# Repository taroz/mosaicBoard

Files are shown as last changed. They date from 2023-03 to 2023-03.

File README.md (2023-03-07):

# mosaic-Board
## Introduction
- **mosaic-Board** = [**mosaic**](https://github.com/septentrio-gnss/mosaicHAT) + **micro SD card** + **Ethernet** + **Case**
- We use [Septentrio's mosaic-X5](https://www.septentrio.com/en/products/gnss-receivers/rover-base-receivers/receivers-module/mosaic) GNSS module which is a **low-cost** and **survey-grade** GNSS receiver
- This project is inspired by [mosaicHAT](https://github.com/septentrio-gnss/mosaicHAT) and extends it further. Thanks to the wonderful project [mosaicHAT](https://github.com/septentrio-gnss/mosaicHAT)!
- License: [Creative Commons Attribution Share-Alike License](https://creativecommons.org/licenses/by-sa/4.0/). and [Open Source HW](https://www.oshwa.org/definition/)  
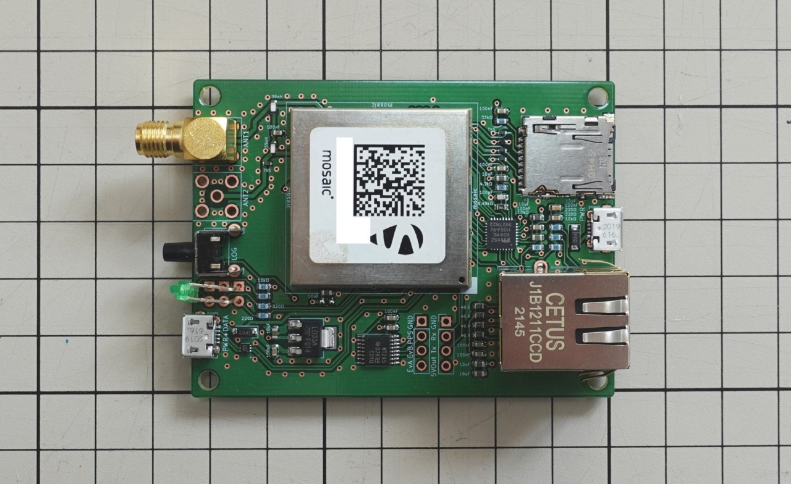
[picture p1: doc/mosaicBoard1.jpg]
 
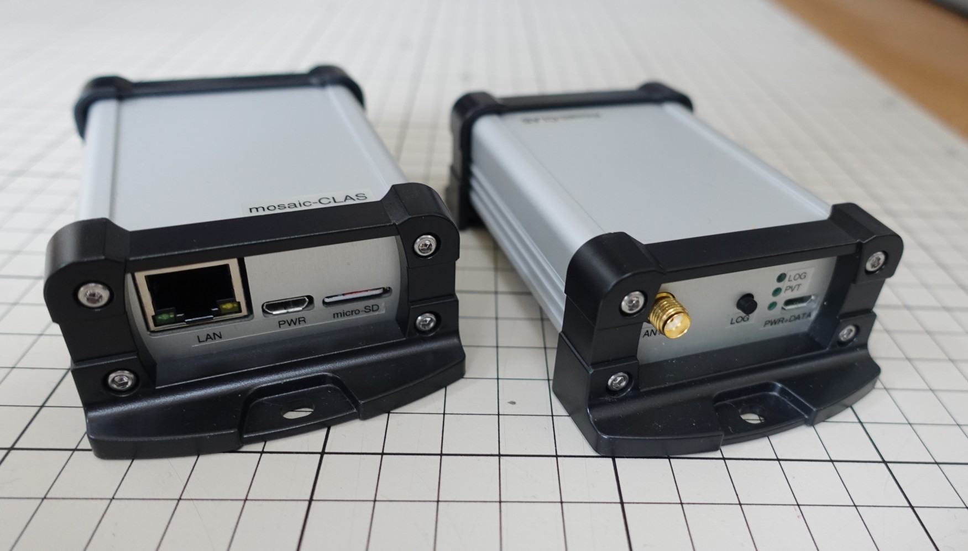
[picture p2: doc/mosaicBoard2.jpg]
 

## Features
- The mosaic-Board has a RJ45 LAN connector and can easily distribute GNSS reference station data over the Internet without a PC by using mosaic's built-in Ntrip Caster or Ntrip Server.
- The micro SD card enables use as a GNSS logger without a PC.

## Board
- The design of the board is based on the original [mosaicHAT](https://github.com/septentrio-gnss/mosaicHAT).
  - RJ45 connector has been added
  - Micro SD card and log button have been added for data logging capability
- [KiCAD files](./board/KiCAD) and [gerber](./board/gerber)
- Bill of Materials (BOM) is [here](./board/BOM.xlsx)                                 
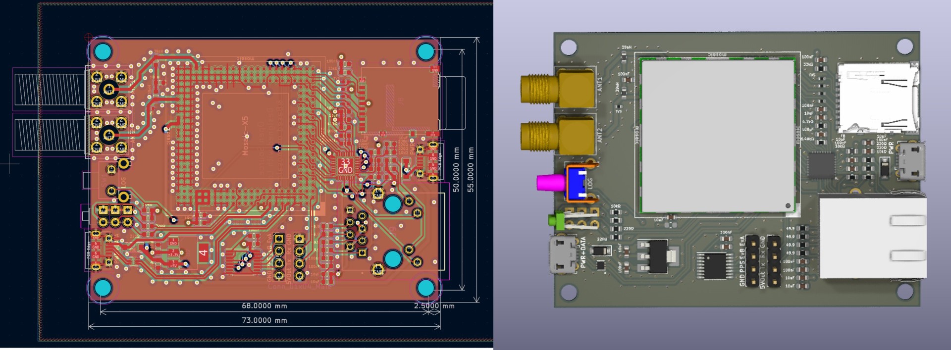
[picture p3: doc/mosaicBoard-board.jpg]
  

## Case
- Metal case design data (Fusion 360, STEP) is [available](./case)
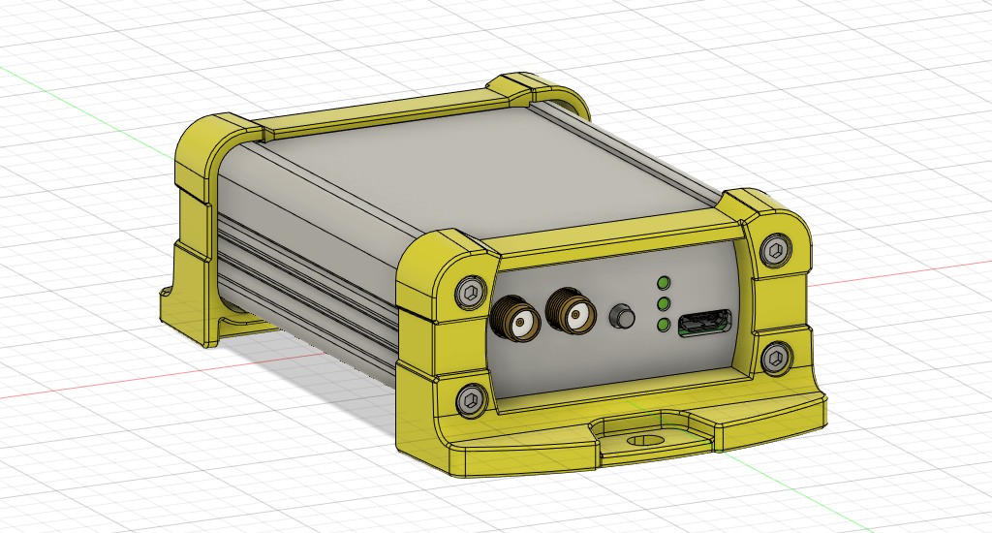
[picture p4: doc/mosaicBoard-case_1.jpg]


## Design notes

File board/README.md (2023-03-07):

# mosaic-Board Design Files
- We used KiCAD 6 for our design. [KiCAD 6 or later](https://www.kicad.org/) must be installed in order to edit the design data.
- BOM
  - `BOM.xlsx` shows the parts to be used and where to obtain them.

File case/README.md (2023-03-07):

# mosaic-Board Case
## Case
- TAKACHI EXP7-3-9, EXPE7-3-9, EXPF7-3-9 or EXEF7-3-9 
  - **EXP7-3-9** https://www.takachi-enclosure.com/products/EXP
  - **EXPE7-3-9** https://www.takachi-enclosure.com/products/EXPE (EMC shield)
  - **EXPF7-3-9** https://www.takachi-enclosure.com/products/EXPF (with flanged frame)
  - **EXEF7-3-9** https://www.takachi-enclosure.com/products/EXEF (EMC shield with flanged frame)
  
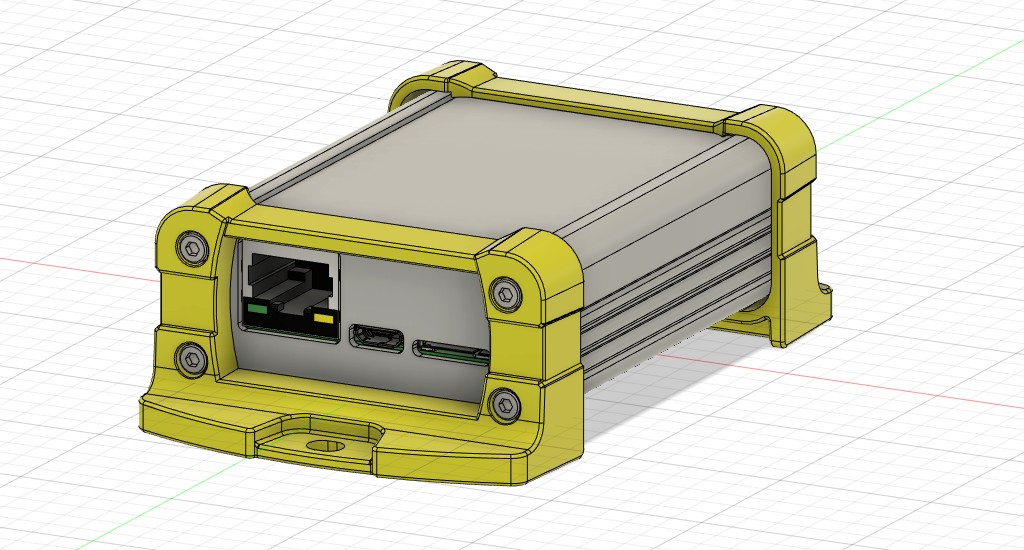
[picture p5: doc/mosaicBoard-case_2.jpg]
  
- Metalworking of the panel is required.

## 3D data
- `Fusion360/mosaicBoard-case.f3z`: Fusion 360 design data
- `mosaicBoard-case.step`: STEP file
- `panel1.step`: Panel STEP file
- `panel2.step`: Panel STEP file

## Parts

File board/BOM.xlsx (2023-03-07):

Designator | Footprint | Quantity | Value | MPN
C1, C12, C14, C15, C16, C19, C3, C4, C5, C8 | C_0603_1608Metric | 10 | 100nF
C10 | C_0603_1608Metric | 1 | 1uF
C11, C13, C18, C2, C6, C9 | C_0603_1608Metric | 6 | 10uF
C17 | C_0603_1608Metric | 1 | 100pF
C7 | C_0603_1608Metric | 1 | un-assembled
D1, D2 | D_SOD-123 | 2 | MBRX120LF-TP | MBRX120LF-TP | https://www.digikey.com/product-detail/en/micro-commercial-co/MBRX120LF-TP/MBRX120LF-TPMSCT-ND/2041570
D10, D11, D12, D13, D9 | R_0402_1005Metric | 5 | D_TVS | SESD0402X1BN-0010-098 | https://www.digikey.com/en/products/detail/littelfuse-inc/SESD0402X1BN-0010-098/5233522
D3 | LED_D1.8mm_W1.8mm_H2.4mm_Horizontal_O1.27mm_Z1.6mm | 1 | LED | TLUG2401 | https://www.digikey.com/en/products/detail/vishay-semiconductor-opto-division/TLUG2401/4074586
D4 | LED_D1.8mm_W1.8mm_H2.4mm_Horizontal_O3.81mm_Z4.9mm | 1 | LED | TLUG2401 | https://www.digikey.com/en/products/detail/vishay-semiconductor-opto-division/TLUG2401/4074586
D5 | LED_D1.8mm_W1.8mm_H2.4mm_Horizontal_O6.35mm_Z8.2mm | 1 | LED | TLUG2401 | https://www.digikey.com/en/products/detail/vishay-semiconductor-opto-division/TLUG2401/4074586
FB1 | L_0603_1608Metric | 1 | Ferrite_Bead_Small | BLM18RK601SN1D | https://www.digikey.com/en/products/detail/murata-electronics/BLM18RK601SN1D/1948332
FL1 | ST_UQFN-6L_1.5x1.7mm_Pitch0.5mm | 1 | ECMF02-2AMX6 | ECMF02-2AMX6 | https://www.digikey.com/en/products/detail/stmicroelectronics/ECMF02-2AMX6/2440273
IC1 | QFN50P500X500X90-33N-D | 1 | KSZ8041NLI-TR | KSZ8041NLI-TR | https://www.digikey.com/en/products/detail/microchip-technology/KSZ8041NLI-TR/1640276
J1, J2 | SMA_Amphenol_132203-12_Horizontal_mod | 2 | Conn_Coaxial | 132136 | https://www.digikey.com/en/products/detail/amphenol-rf/132136/1011909
J10, J3 | USB_Micro-B_Molex-105017-0001 | 2 | USB_B_Micro | 1050170001 | https://www.digikey.com/en/products/detail/molex/1050170001/2350832
J4, J5 | PinHeader_1x04_P2.54mm_Vertical | 2 | Conn_01x04_Male
J8 | microSD_HC_Hirose_DM3AT-SF-PEJM5 | 1 | Micro_SD_Card | DM3AT-SF-PEJM5 | https://www.digikey.com/en/products/detail/hirose-electric-co-ltd/DM3AT-SF-PEJM5/2533565
J9 | J1B1211CCD | 1 | J1B1211CCD | J1B1211CCD | https://www.digikey.com/en/products/detail/wiznet/J1B1211CCD/7604176
L1, L2 | L_0603_1608Metric | 2 | 39nH
R1, R15, R2, R4, R5 | R_0603_1608Metric | 5 | 220
R10, R3, R8, R9 | R_0603_1608Metric | 4 | 49.9
R11, R14, R7 | R_0603_1608Metric | 3 | 10K
R12 | R_0603_1608Metric | 1 | 6.49K
R13 | R_0603_1608Metric | 1 | 4.7K
R6 | R_0603_1608Metric | 1 | 33K
SW1 | SW_Tactile_SKHH_Angled | 1 | SW_Push | SKHHLQA010 | https://www.mouser.com/ProductDetail/Alps-Alpine/SKHHLQA010
U1 | mosaic_X5 | 1 | mosaic-X5 | 410322 | https://www.digikey.com/en/products/detail/septentrio-inc/410322/12503897
U2 | SOT-223 | 1 | LD1117AS33TR | LD1117AS33TR | https://www.digikey.com/product-detail/en/stmicroelectronics/LD1117AS33TR/497-1228-1-ND/586228
U3 | TSSOP-16_4.4x5mm_P0.65mm | 1 | SN74AVC4T245PW | SN74AVC4T245PWR | https://www.digikey.com/product-detail/en/texas-instruments/SN74AVC4T245PWR/296-18056-1-ND/770944
Case |  | 1 | TAKACHI | EXEF7-3-9 | https://www.takachi-enclosure.com/products/EXEF

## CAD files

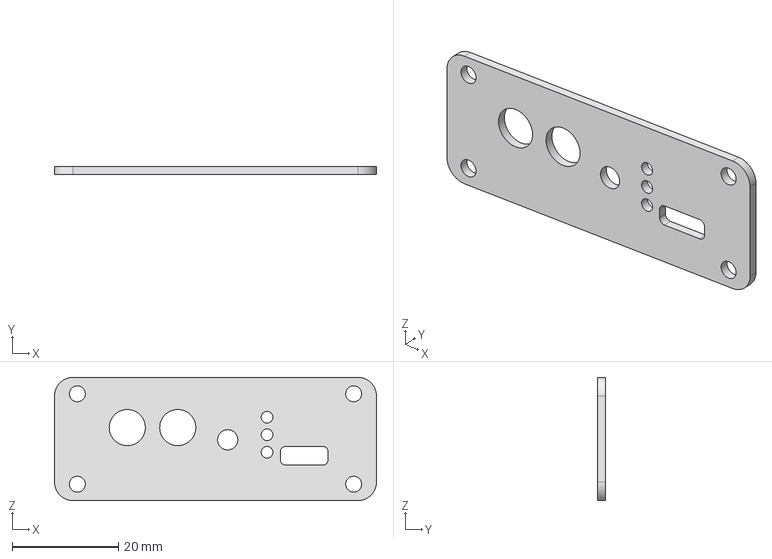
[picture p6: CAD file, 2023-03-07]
case/panel1.step
60.6 x 1.50 x 23.2 mm

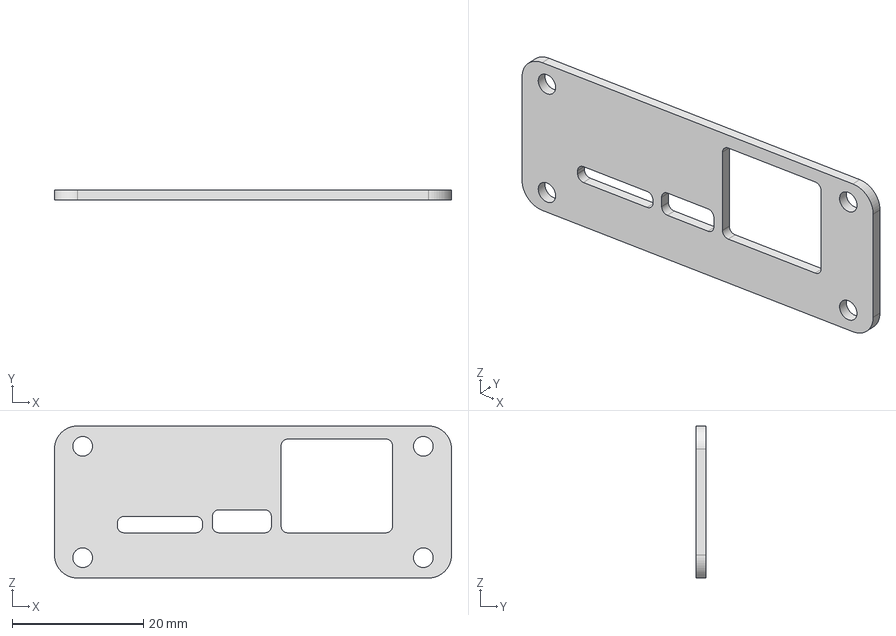
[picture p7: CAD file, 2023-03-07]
case/panel2.step
60.6 x 1.50 x 23.2 mm

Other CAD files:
case/Fusion360/mosaicBoard-case.f3z

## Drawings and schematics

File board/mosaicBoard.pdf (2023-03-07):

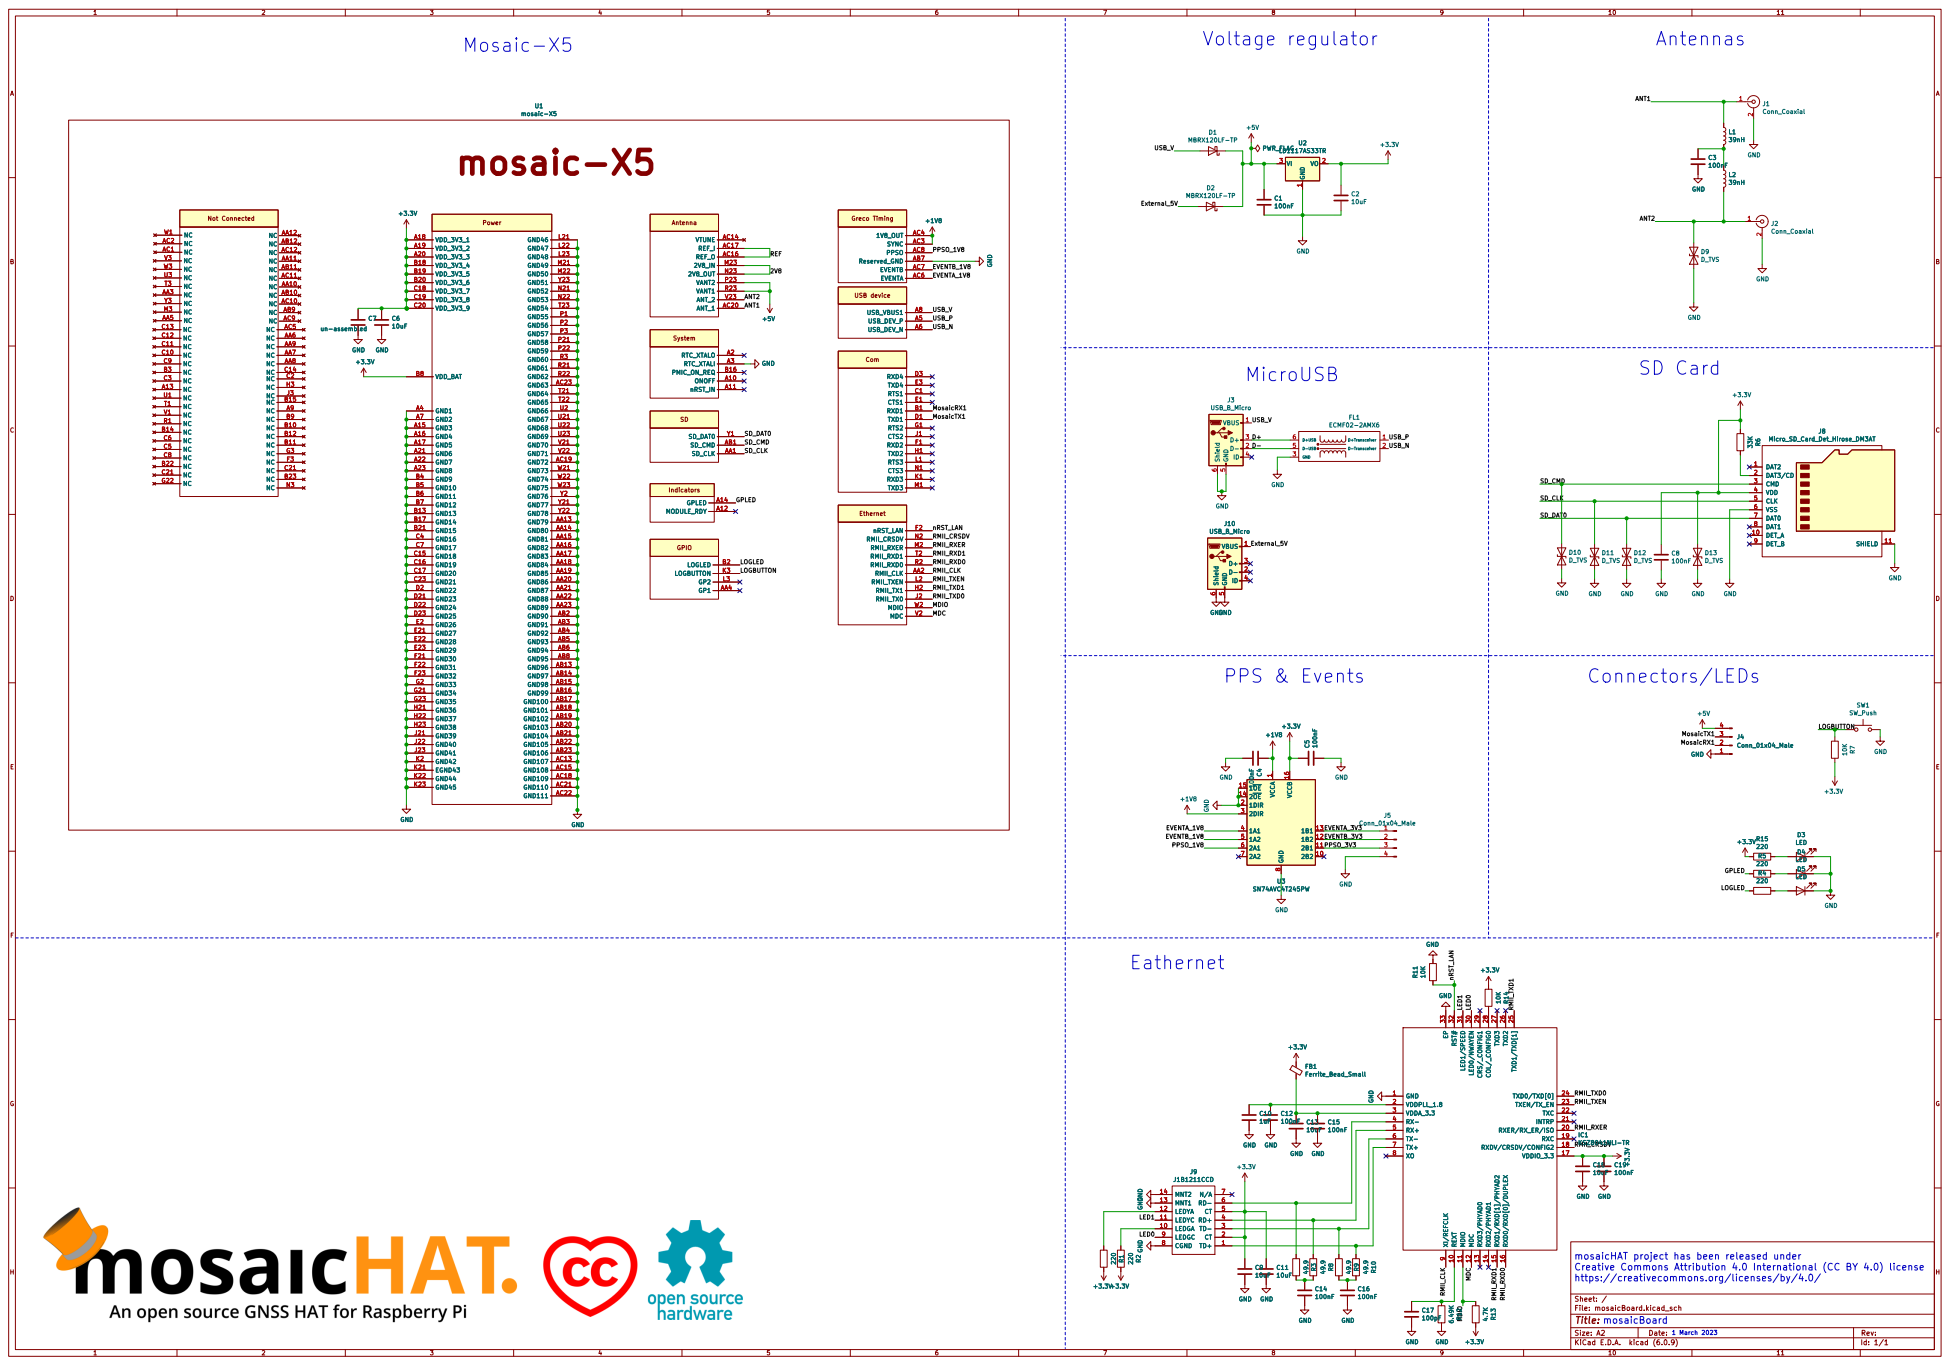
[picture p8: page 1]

mosaicHAT project has been released under
Creative Commons Attribution 4.0 International (CC BY 4.0) license
https://creativecommons.org/licenses/by/4.0/ 1 March 2023 mosaicBoard

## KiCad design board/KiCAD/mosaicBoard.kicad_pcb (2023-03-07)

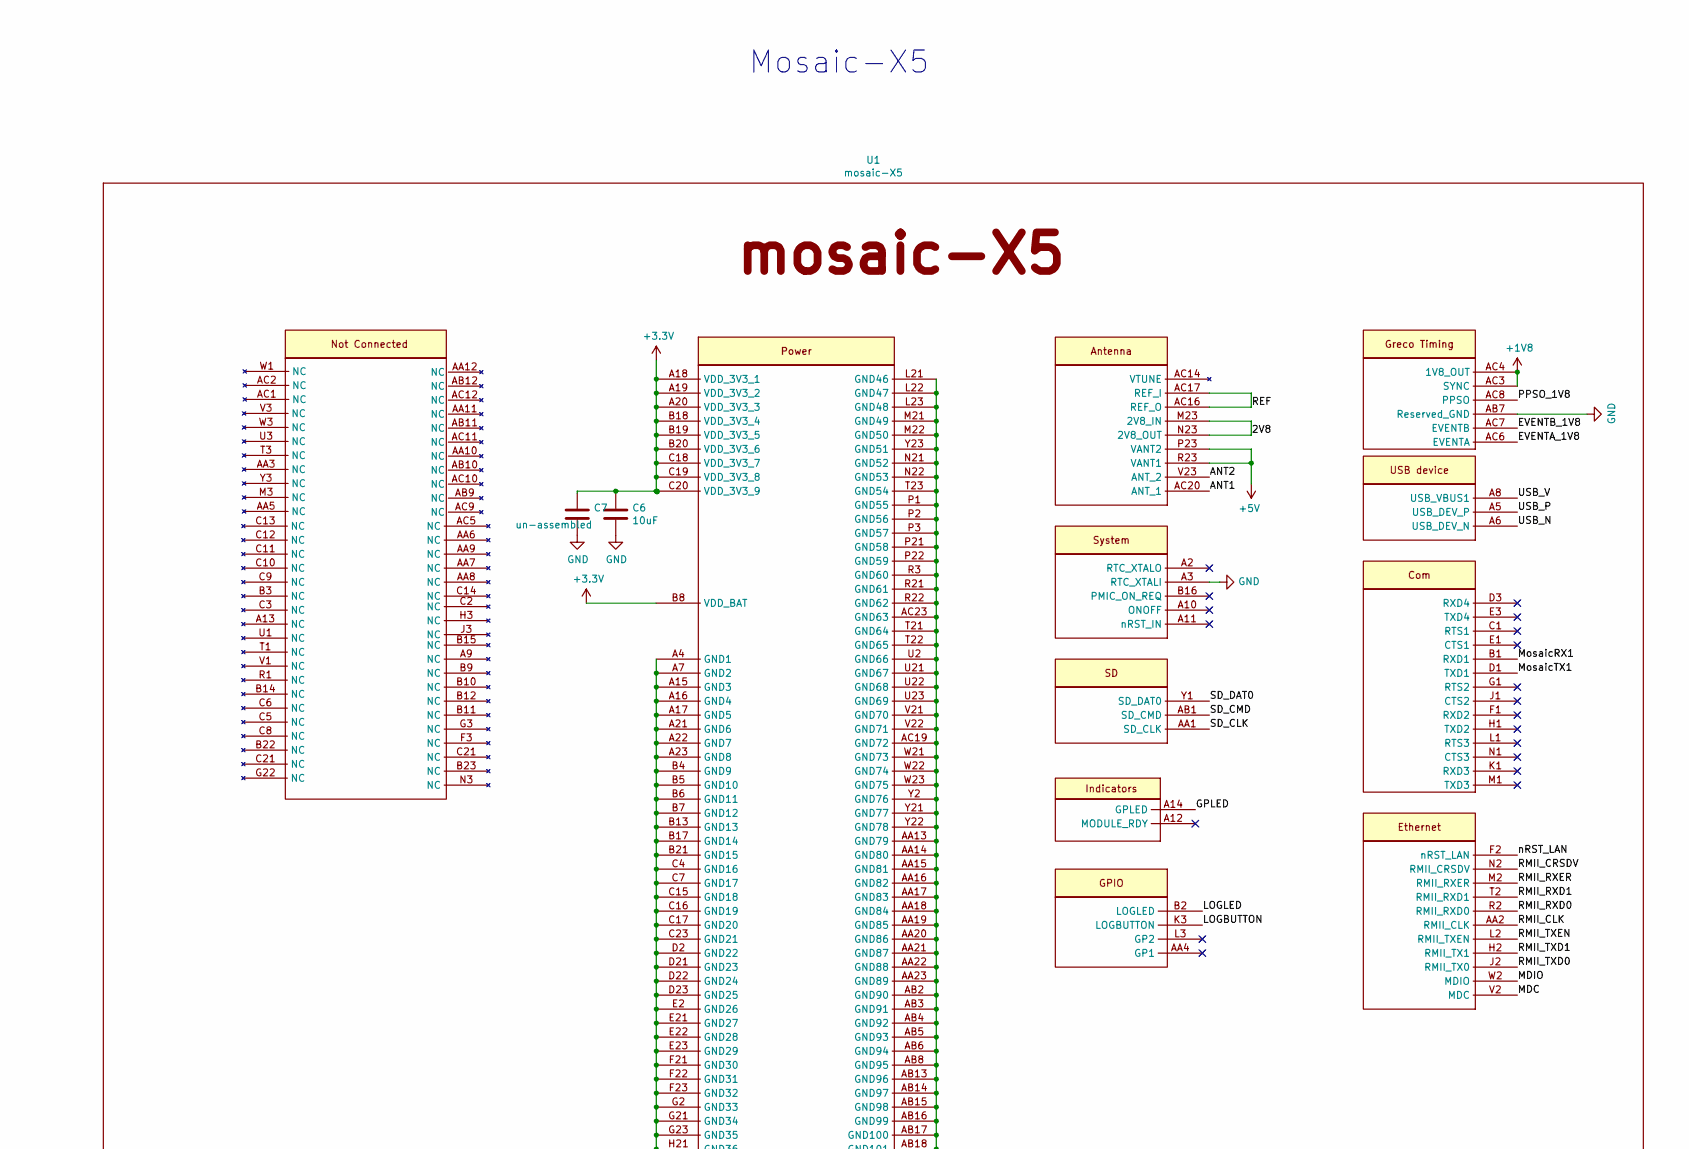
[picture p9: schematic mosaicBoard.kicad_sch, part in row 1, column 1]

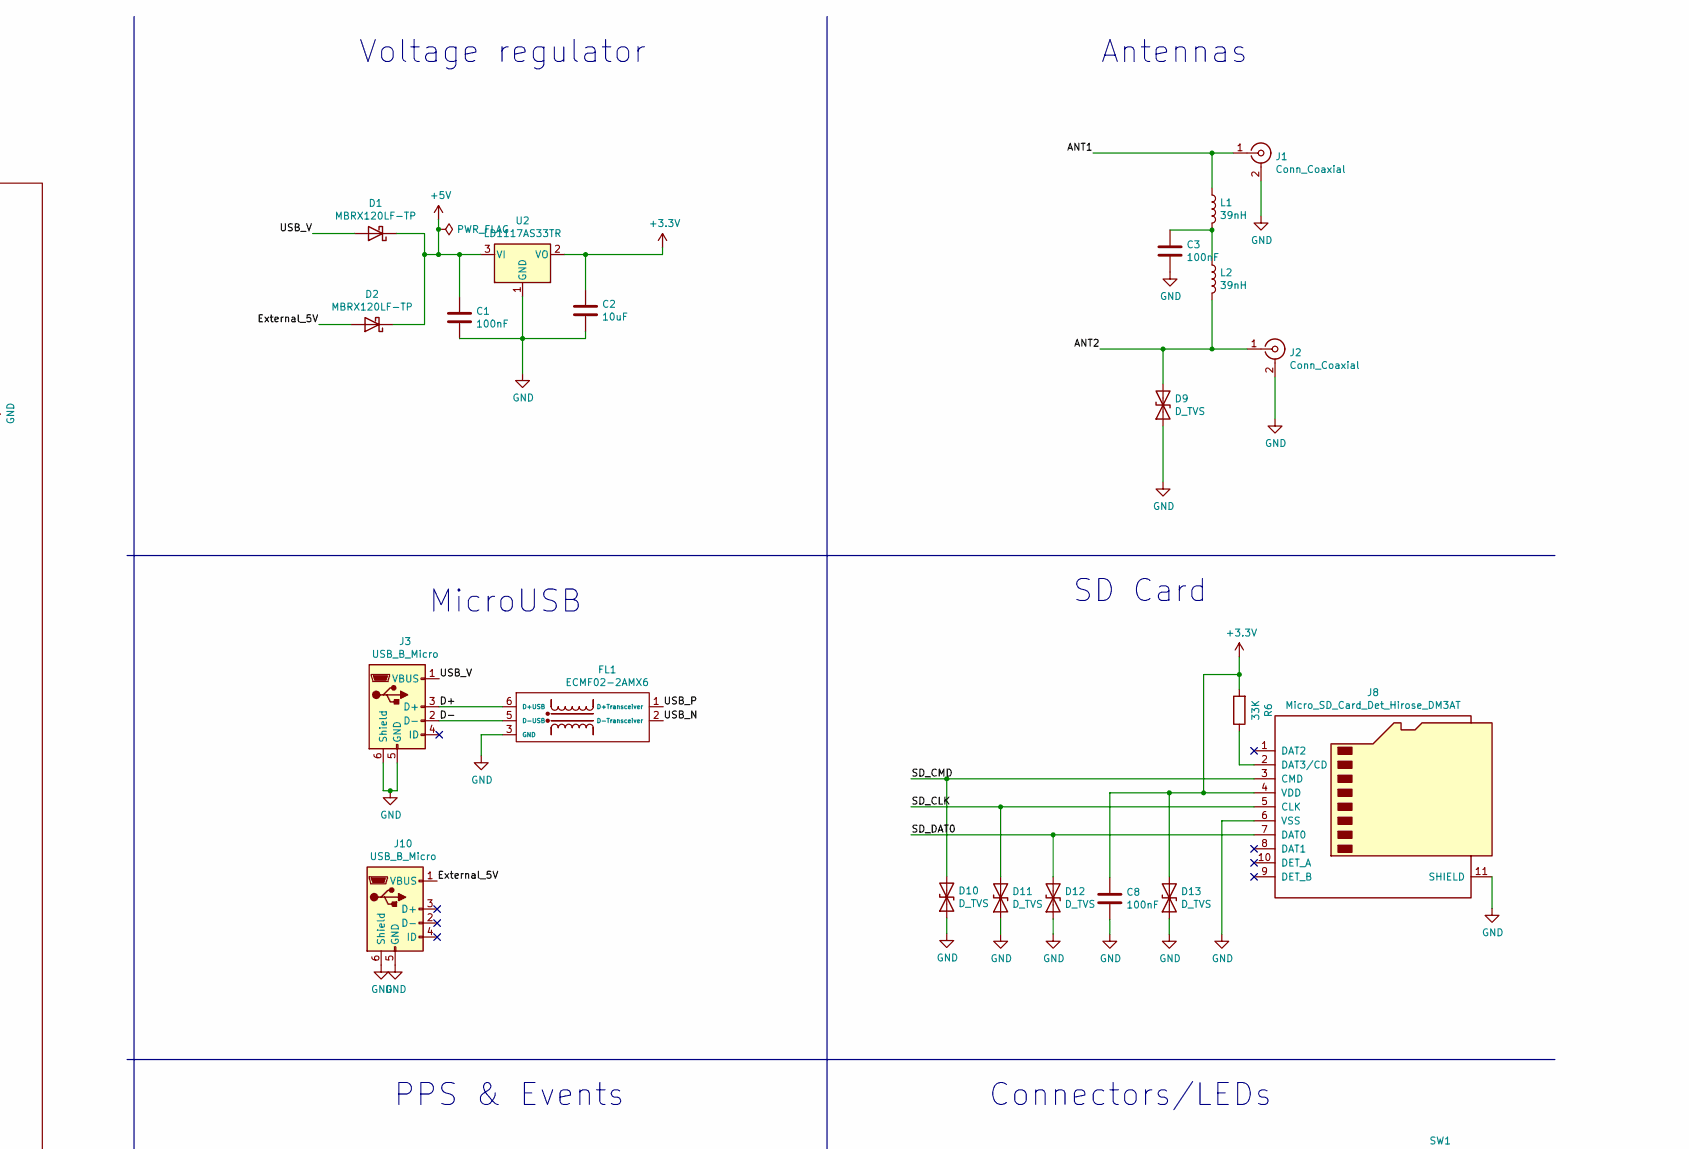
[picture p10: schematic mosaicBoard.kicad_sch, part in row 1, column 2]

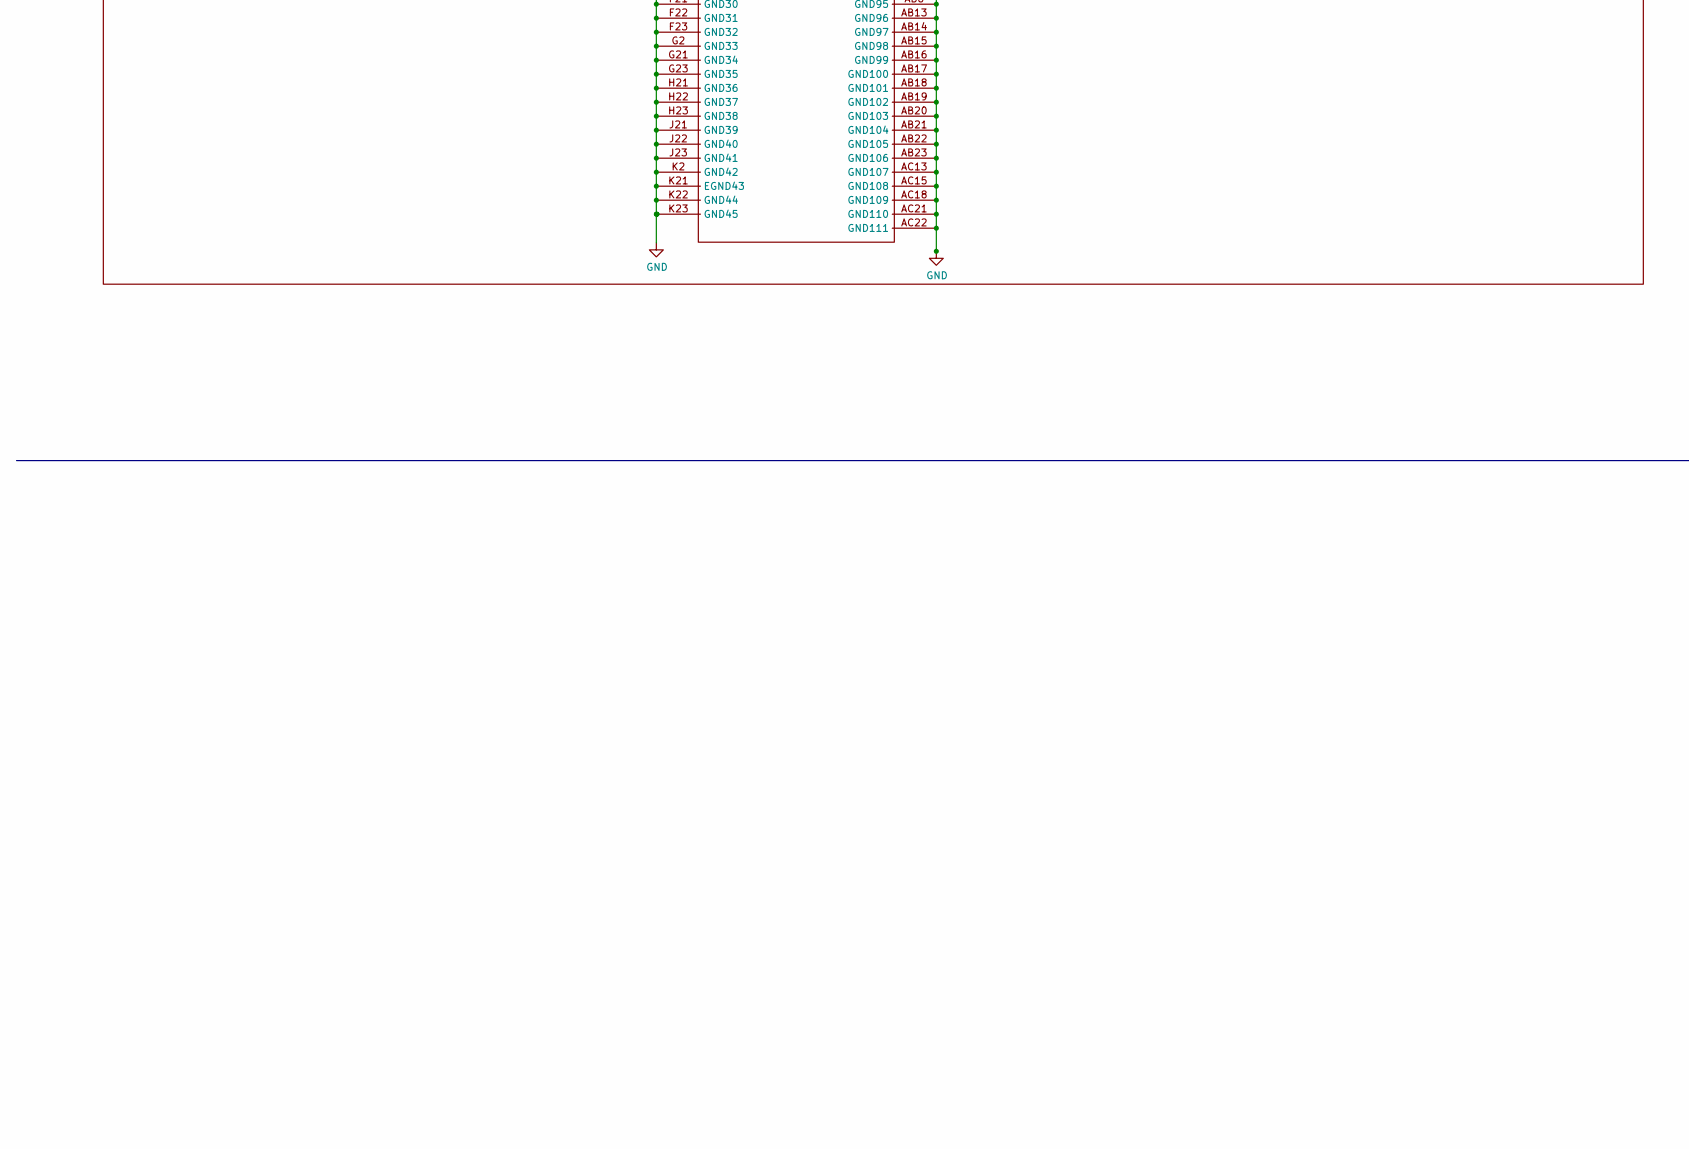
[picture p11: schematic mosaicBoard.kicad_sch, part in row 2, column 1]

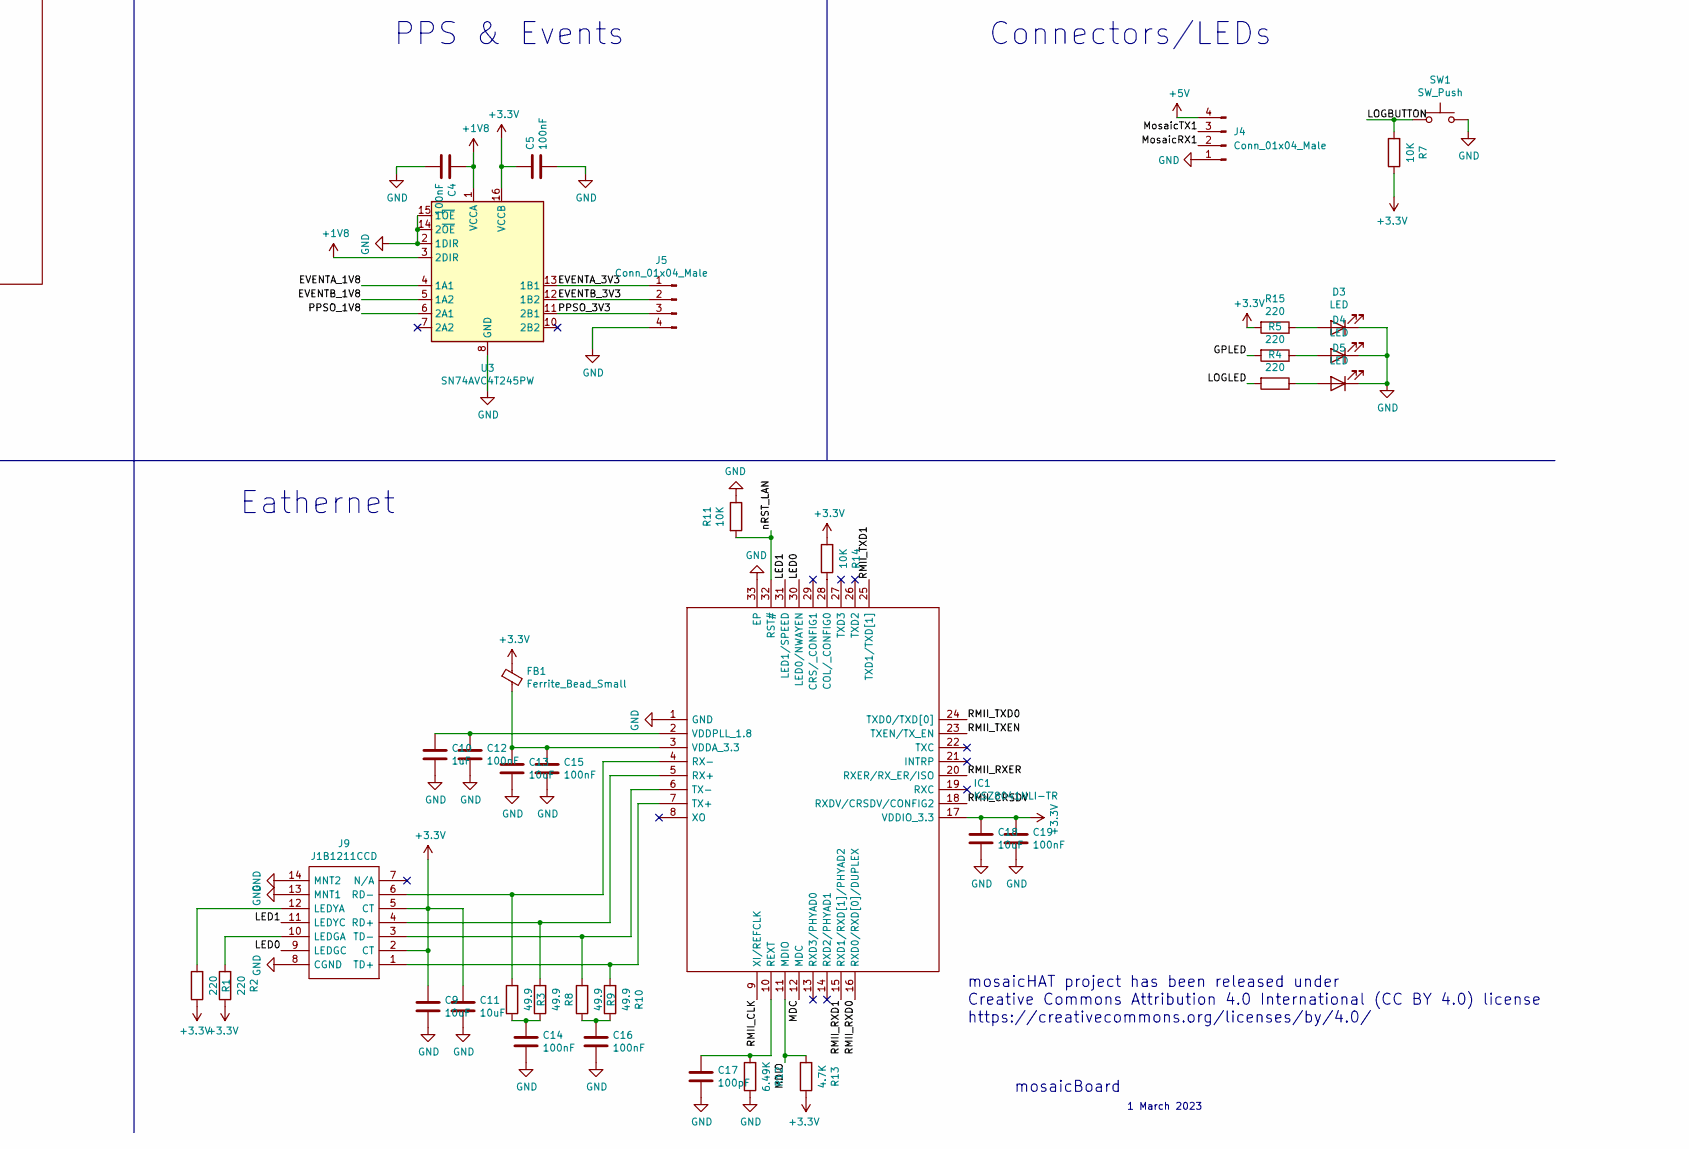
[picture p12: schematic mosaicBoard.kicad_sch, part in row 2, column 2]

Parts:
C1, C3, C4, C5, C8, C12, C14, C15, C16, C19: 100nF; C_0603_1608Metric
C2, C6, C9, C11, C13, C18: 10uF; C_0603_1608Metric
C7: un-assembled; C_0603_1608Metric
C10: 1uF; C_0603_1608Metric
C17: 100pF; C_0603_1608Metric
D1, D2: MBRX120LF-TP; D_SOD-123
D3: LED; LED_D1.8mm_W1.8mm_H2.4mm_Horizontal_O1.27mm_Z1.6mm
D4: LED; LED_D1.8mm_W1.8mm_H2.4mm_Horizontal_O3.81mm_Z4.9mm
D5: LED; LED_D1.8mm_W1.8mm_H2.4mm_Horizontal_O6.35mm_Z8.2mm
D9, D10, D11, D12, D13: D_TVS; R_0402_1005Metric
FB1: Ferrite_Bead_Small; L_0603_1608Metric
FL1: ECMF02-2AMX6; ST_UQFN-6L_1.5x1.7mm_Pitch0.5mm
IC1: KSZ8041NLI-TR; QFN50P500X500X90-33N-D; Mouser Part Number 998-KSZ8041NLITR
J1, J2: Conn_Coaxial; SMA_Amphenol_132203-12_Horizontal_mod
J3, J10: USB_B_Micro; USB_Micro-B_Molex-105017-0001
J4, J5: Conn_01x04_Male; PinHeader_1x04_P2.54mm_Vertical
J8: Micro_SD_Card_Det_Hirose_DM3AT; microSD_HC_Hirose_DM3AT-SF-PEJM5
J9: J1B1211CCD; Mouser Part Number 950-J1B1211CCD
L1, L2: 39nH; L_0603_1608Metric
R1, R2, R4, R5, R15: 220; R_0603_1608Metric
R3, R8, R9, R10: 49.9; R_0603_1608Metric
R6: 33K; R_0603_1608Metric
R7, R11, R14: 10K; R_0603_1608Metric
R12: 6.49K; R_0603_1608Metric
R13: 4.7K; R_0603_1608Metric
SW1: SW_Push; SW_Tactile_SKHH_Angled
U1: mosaic-X5; mosaic_X5
U2: LD1117AS33TR; SOT-223
U3: SN74AVC4T245PW; TSSOP-16_4.4x5mm_P0.65mm

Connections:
+1V8: C4.1, U1.AC3 (SYNC), U1.AC4 (1V8_OUT), U3.1 (VCCA), U3.3 (2DIR)
+3.3V: C2.1, C5.1, C6.1, C7.1, C8.1, C9.1, C11.1, C18.1, C19.1, D13.2 (A2), FB1.1, IC1.17 (VDDIO_3.3), J8.4 (VDD), J9.2 (CT), J9.5 (CT), R1.1, R2.1, R6.2, R7.1, R13.1, R14.2, R15.2, U1.A18 (VDD_3V3_1), U1.A19 (VDD_3V3_2), U1.A20 (VDD_3V3_3), U1.B8 (VDD_BAT), U1.B18 (VDD_3V3_4), U1.B19 (VDD_3V3_5), U1.B20 (VDD_3V3_6), U1.C18 (VDD_3V3_7), U1.C19 (VDD_3V3_8), U1.C20 (VDD_3V3_9), U2.2 (VO), U3.16 (VCCB)
+5V: C1.1, D1.1 (K), D2.1 (K), J4.4, U1.P23 (VANT2), U1.R23 (VANT1), U2.3 (VI)
/2V8: U1.M23 (2V8_IN), U1.N23 (2V8_OUT)
/ANT1: J1.1 (In), L1.1, U1.AC20 (ANT_1)
/ANT2: D9.2 (A2), J2.1 (In), L2.2, U1.V23 (ANT_2)
/D+: FL1.6 (D+USB), J3.3 (D+)
/D-: FL1.5 (D-USB), J3.2 (D-)
/EVENTA_1V8: U1.AC6 (EVENTA), U3.4 (1A1)
/EVENTA_3V3: J5.1, U3.13 (1B1)
/EVENTB_1V8: U1.AC7 (EVENTB), U3.5 (1A2)
/EVENTB_3V3: J5.2, U3.12 (1B2)
/External_5V: D2.2 (A), J10.1 (VBUS)
/GPLED: R5.2, U1.A14 (GPLED)
/LED0: IC1.30 (LED0/NWAYEN), J9.9 (LEDGC)
/LED1: IC1.31 (LED1/SPEED), J9.11 (LEDYC)
/LOGBUTTON: R7.2, SW1.1, U1.K3 (LOGBUTTON)
/LOGLED: R4.2, U1.B2 (LOGLED)
/MDC: IC1.12 (MDC), U1.V2 (MDC)
/MDIO: IC1.11 (MDIO), R13.2, U1.W2 (MDIO)
/MosaicRX1: J4.2, U1.B1 (RXD1)
/MosaicTX1: J4.3, U1.D1 (TXD1)
/PPSO_1V8: U1.AC8 (PPSO), U3.6 (2A1)
/PPSO_3V3: J5.3, U3.11 (2B1)
/REF: U1.AC16 (REF_O), U1.AC17 (REF_I)
/RMII_CLK: IC1.9 (XI/REFCLK), U1.AA2 (RMII_CLK)
/RMII_CRSDV: IC1.18 (RXDV/CRSDV/CONFIG2), U1.N2 (RMII_CRSDV)
/RMII_RXD0: IC1.16 (RXD0/RXD[0]/DUPLEX), U1.R2 (RMII_RXD0)
/RMII_RXD1: IC1.15 (RXD1/RXD[1]/PHYAD2), U1.T2 (RMII_RXD1)
/RMII_RXER: IC1.20 (RXER/RX_ER/ISO), U1.M2 (RMII_RXER)
/RMII_TXD0: IC1.24 (TXD0/TXD[0]), U1.J2 (RMII_TX0)
/RMII_TXD1: IC1.25 (TXD1/TXD[1]), U1.H2 (RMII_TX1)
/RMII_TXEN: IC1.23 (TXEN/TX_EN), U1.L2 (RMII_TXEN)
/SD_CLK: D11.2 (A2), J8.5 (CLK), U1.AA1 (SD_CLK)
/SD_CMD: D10.2 (A2), J8.3 (CMD), U1.AB1 (SD_CMD)
/SD_DAT0: D12.2 (A2), J8.7 (DAT0), U1.Y1 (SD_DAT0)
/USB_N: FL1.2 (D-Transceiver), U1.A6 (USB_DEV_N)
/USB_P: FL1.1 (D+Transceiver), U1.A5 (USB_DEV_P)
/USB_V: D1.2 (A), J3.1 (VBUS), U1.A8 (USB_VBUS1)
/nRST_LAN: IC1.32 (RST#), R11.2, U1.F2 (nRST_LAN)
GND: C1.2, C2.2, C3.2, C4.2, C5.2, C6.2, C7.2, C8.2, C9.2, C10.2, C11.2, C12.2, C13.2, C14.2, C15.2, C16.2, C17.2, C18.2, C19.2, D3.1 (K), D4.1 (K), D5.1 (K), D9.1 (A1), D10.1 (A1), D11.1 (A1), D12.1 (A1), D13.1 (A1), FL1.3 (GND), IC1.1 (GND), IC1.33 (EP), J1.2 (Ext), J2.2 (Ext), J3.5 (GND), J3.6 (Shield), J4.1, J5.4, J8.6 (VSS), J8.11 (SHIELD), J9.8 (CGND), J9.13 (MNT1), J9.14 (MNT2), J10.5 (GND), J10.6 (Shield), R11.1, R12.1, SW1.2, U1.A3 (RTC_XTALI), U1.A4 (GND1), U1.A7 (GND2), U1.A15 (GND3), U1.A16 (GND4), U1.A17 (GND5), U1.A21 (GND6), U1.A22 (GND7), U1.A23 (GND8), U1.AA13 (GND79), U1.AA14 (GND80), U1.AA15 (GND81), U1.AA16 (GND82), U1.AA17 (GND83), U1.AA18 (GND84), U1.AA19 (GND85), U1.AA20 (GND86), U1.AA21 (GND87), U1.AA22 (GND88), U1.AA23 (GND89), U1.AB2 (GND90), U1.AB3 (GND91), U1.AB4 (GND92), U1.AB5 (GND93), U1.AB6 (GND94), U1.AB7 (Reserved_GND), U1.AB8 (GND95), U1.AB13 (GND96), U1.AB14 (GND97), U1.AB15 (GND98), U1.AB16 (GND99), U1.AB17 (GND100), U1.AB18 (GND101), U1.AB19 (GND102), U1.AB20 (GND103), U1.AB21 (GND104), U1.AB22 (GND105), U1.AB23 (GND106), U1.AC13 (GND107), U1.AC15 (GND108), U1.AC18 (GND109), U1.AC19 (GND72), U1.AC21 (GND110), U1.AC22 (GND111), U1.AC23 (GND63), U1.B4 (GND9), U1.B5 (GND10), U1.B6 (GND11), U1.B7 (GND12), U1.B13 (GND13), U1.B17 (GND14), U1.B21 (GND15), U1.C4 (GND16), U1.C7 (GND17), U1.C15 (GND18), U1.C16 (GND19), U1.C17 (GND20), U1.C23 (GND21), U1.D2 (GND22), U1.D21 (GND23), U1.D22 (GND24), U1.D23 (GND25), U1.E2 (GND26), U1.E21 (GND27), U1.E22 (GND28), U1.E23 (GND29), U1.F21 (GND30), U1.F22 (GND31), U1.F23 (GND32), U1.G2 (GND33), U1.G21 (GND34), U1.G23 (GND35), U1.H21 (GND36), U1.H22 (GND37), U1.H23 (GND38), U1.J21 (GND39), U1.J22 (GND40), U1.J23 (GND41), U1.K2 (GND42), U1.K21 (EGND43), U1.K22 (GND44), U1.K23 (GND45), U1.L21 (GND46), U1.L22 (GND47), U1.L23 (GND48), U1.M21 (GND49), U1.M22 (GND50), U1.N21 (GND52), U1.N22 (GND53), U1.P1 (GND55), U1.P2 (GND56), U1.P3 (GND57), U1.P21 (GND58), U1.P22 (GND59), U1.R3 (GND60), U1.R21 (GND61), U1.R22 (GND62), U1.T21 (GND64), U1.T22 (GND65), U1.T23 (GND54), U1.U2 (GND66), U1.U21 (GND67), U1.U22 (GND68), U1.U23 (GND69), U1.V21 (GND70), U1.V22 (GND71), U1.W21 (GND73), U1.W22 (GND74), U1.W23 (GND75), U1.Y2 (GND76), U1.Y21 (GND77), U1.Y22 (GND78), U1.Y23 (GND51), U2.1 (GND), U3.2 (1DIR), U3.8 (GND), U3.9 (GND), U3.14 (2~OE), U3.15 (1~OE)
unnamed: C3.1, L1.2, L2.1
unnamed: C10.1, C12.1, IC1.2 (VDDPLL_1.8)
unnamed: C13.1, C15.1, FB1.2, IC1.3 (VDDA_3.3)
unnamed: C14.1, R3.1, R8.1
unnamed: C16.1, R9.1, R10.1
unnamed: C17.1, IC1.10 (REXT), R12.2
unnamed: D3.2 (A), R15.1
unnamed: D4.2 (A), R5.1
unnamed: D5.2 (A), R4.1
unnamed: IC1.4 (RX-), J9.6 (RD-), R3.2
unnamed: IC1.5 (RX+), J9.4 (RD+), R8.2
unnamed: IC1.6 (TX-), J9.3 (TD-), R9.2
unnamed: IC1.7 (TX+), J9.1 (TD+), R10.2
unnamed: IC1.28 (COL/_CONFIG0), R14.1
unnamed: J8.2 (DAT3/CD), R6.1
unnamed: J9.10 (LEDGA), R2.2
unnamed: J9.12 (LEDYA), R1.2

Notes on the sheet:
mosaicHAT project has been released under Creative Commons Attribution 4.0 International (CC BY 4.0) license https://creativecommons.org/licenses/by/4.0/
SD Card
1 March 2023
Eathernet
Voltage regulator
PPS & Events
Mosaic-X5
Antennas
mosaicBoard
Connectors/LEDs
MicroUSB

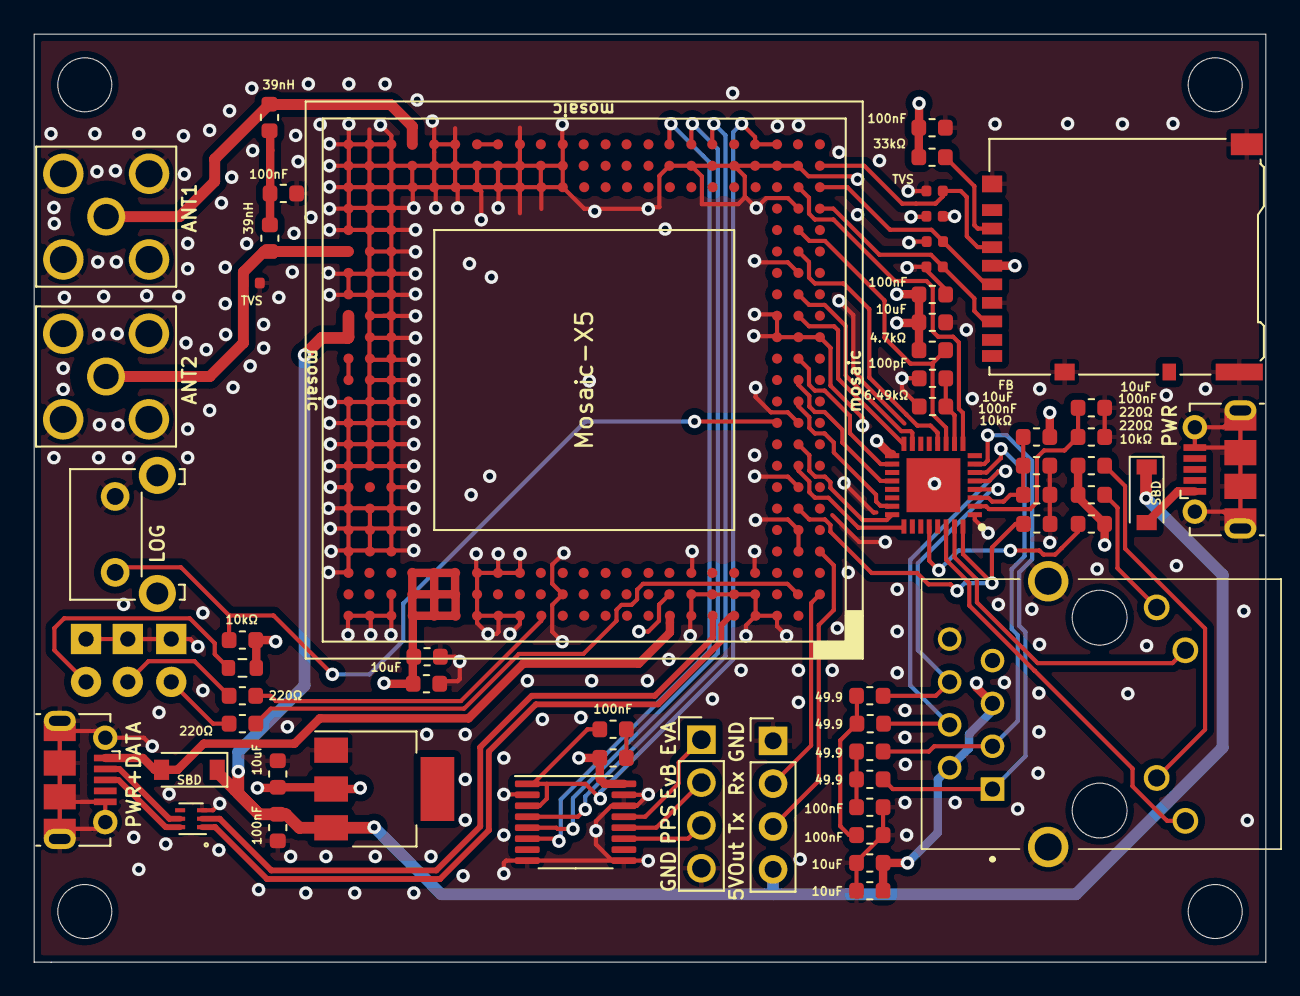
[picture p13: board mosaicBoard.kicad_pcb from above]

Board: 4 copper layers, 73.0 x 55.0 mm, 61 parts (0 on the bottom side), 58 nets.
